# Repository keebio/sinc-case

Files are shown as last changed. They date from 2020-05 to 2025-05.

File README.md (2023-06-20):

# Sinc Keyboard Case

Here are the case design files for the [Sinc](https://keeb.io/products/sinc-split-staggered-75-keyboard). The .ai files have multiple layers to toggle on/off to generate the correct set of plates/mid-layers/etc.

It's suggested to use the enclosed design.

## Plate Files

In the [plates](plates/) folder, there are DXF files of the switch plates and bottom plates. These are the same design as the FR4 plates that are sold. The switch plates are designed for 1.5-1.6mm thickness.
## Enclosed Design

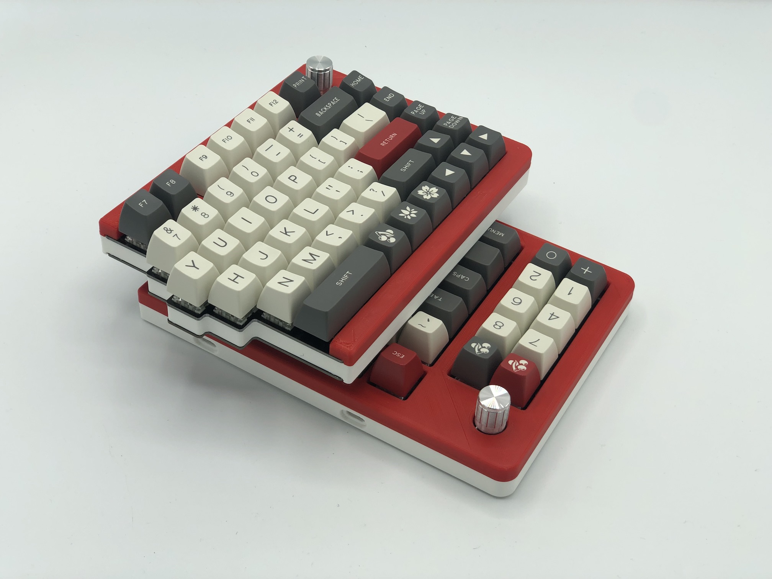
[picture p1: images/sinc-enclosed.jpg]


In the [enclosed-case](enclosed-case/) folder, there are STL files for a design where the FR4 switch and bottom plates are used but have their sides covered. The top shell has been designed to be threaded into directly from underneath using long M2 screws.

For the Rev. 2-4, you will need [M2 screws that are 16mm](https://keeb.io/products/m2-screws-and-standoffs?variant=39401487040606) in length. For Rev. 1, due to the thicker mid layer, you will need 20mm screws.

## SKUF Alignment Guide/Tool

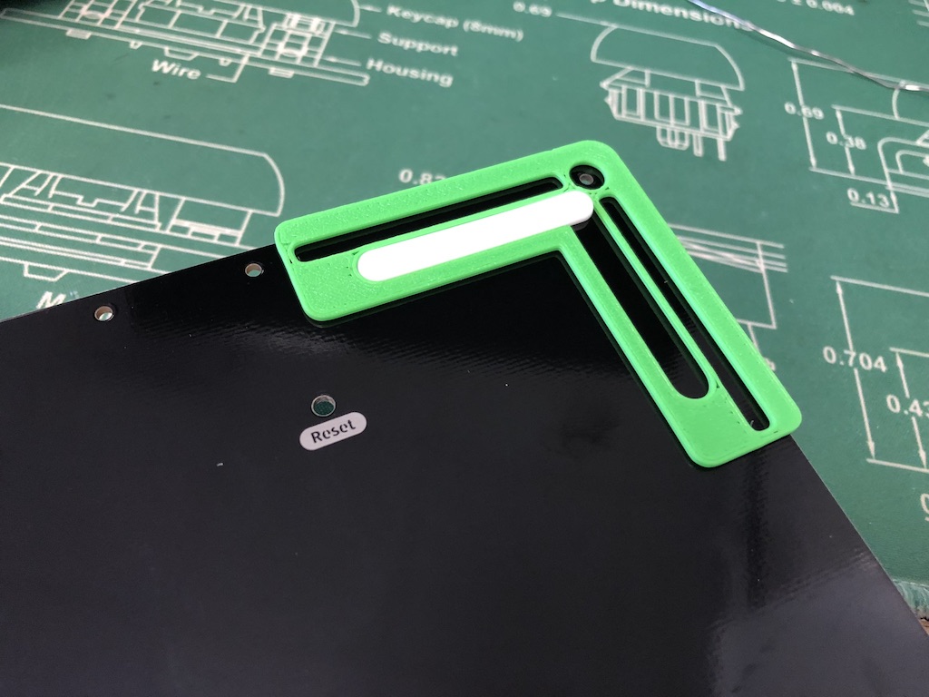
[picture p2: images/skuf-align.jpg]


For aligning the SKUF feet so that they are straight, you can print off this tool to help you apply the SKUF feet better: [SKUF Alignment Guide](SKUF%20Alignment%20Guide.stl)

## Older Design

The original case design can be found in the [older-design](older-design/) folder. The design there can be used to make a stacked acrylic case

## License

These case files are released under the MIT License.

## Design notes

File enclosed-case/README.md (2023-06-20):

Rev. 2-4 have the same PCB shape, so Rev. 2 files work fine with Rev. 3 and 4.

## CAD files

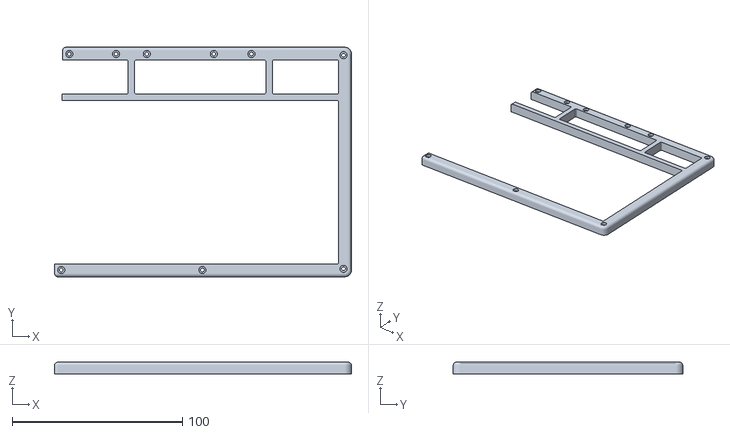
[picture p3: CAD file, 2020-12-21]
Top Shell - Right Full.stl
174.7 x 135.1 x 7.00

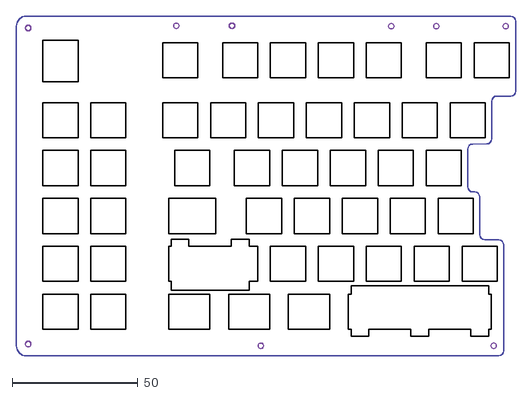
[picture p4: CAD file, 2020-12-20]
plates/5mm-plate/sinc-switch-plate-5mm-left-full.dxf
198.5 x 135.1

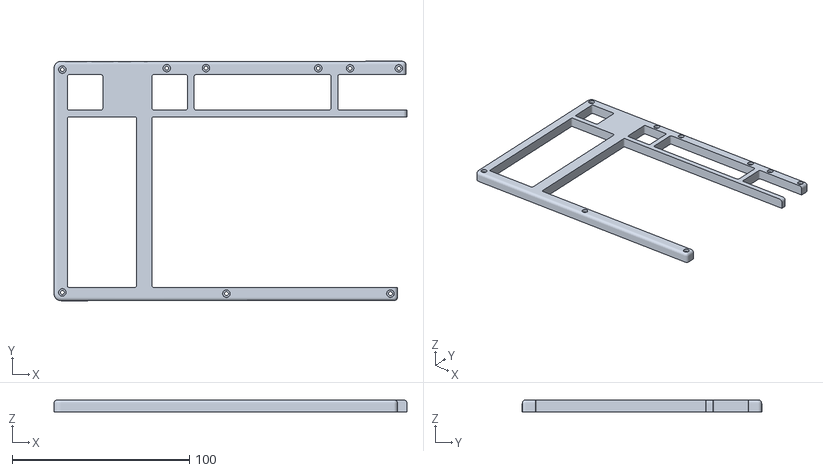
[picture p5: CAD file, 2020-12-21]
Top Shell - Left Full.stl
199.1 x 135.1 x 7.00

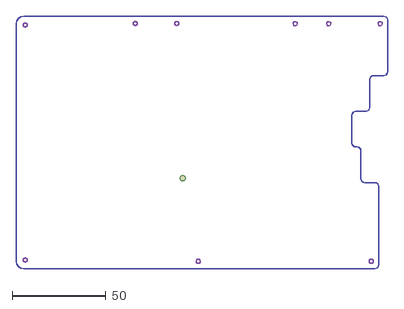
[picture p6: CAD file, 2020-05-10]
plates/sinc-bottom-plate-left-full.dxf
198.5 x 135.1

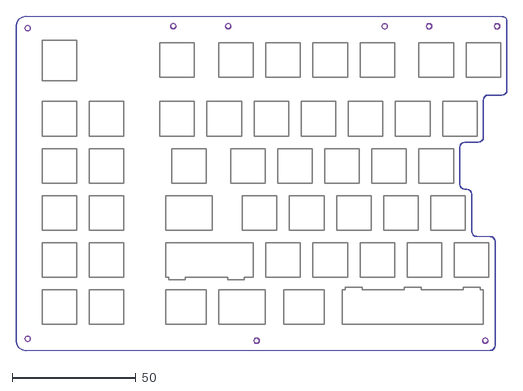
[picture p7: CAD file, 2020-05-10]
plates/sinc-switch-plate-left-full.dxf
198.5 x 135.1

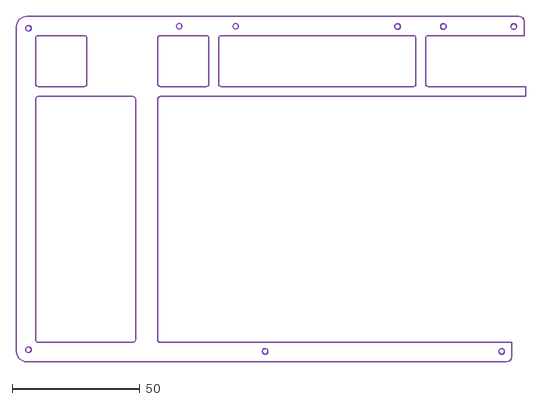
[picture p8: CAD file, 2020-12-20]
sinc-top-shell-left-full.dxf
199.1 x 135.1

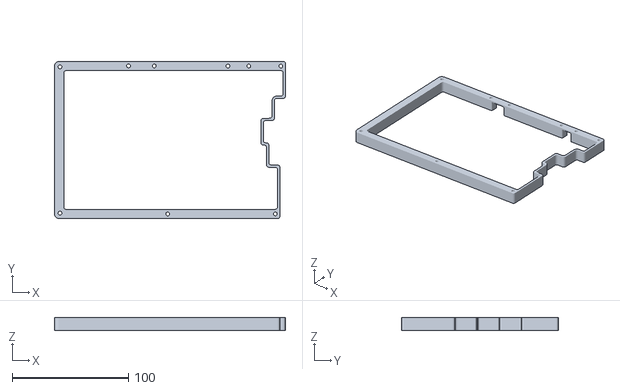
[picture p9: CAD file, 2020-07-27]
Mid - Left Full.stl
198.5 x 135.1 x 11.0

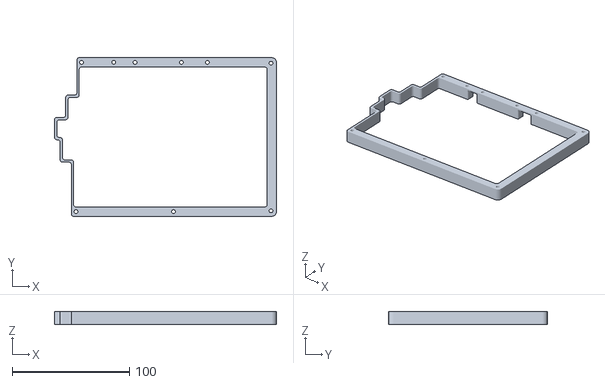
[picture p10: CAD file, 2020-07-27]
Mid - Right Full.stl
189.0 x 135.1 x 11.0

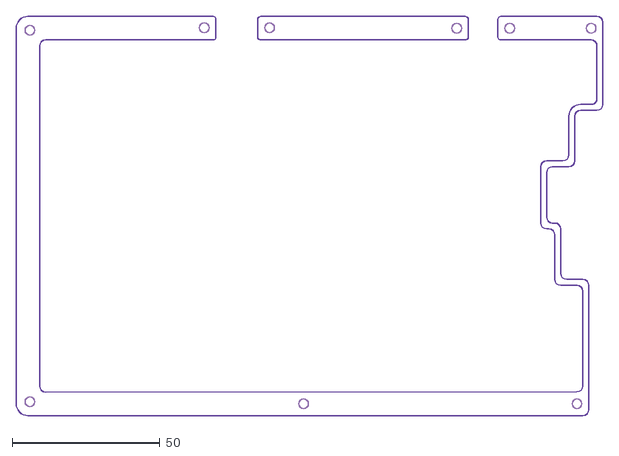
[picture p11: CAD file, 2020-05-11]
sinc-mid-layer-left-full.dxf
198.5 x 135.1

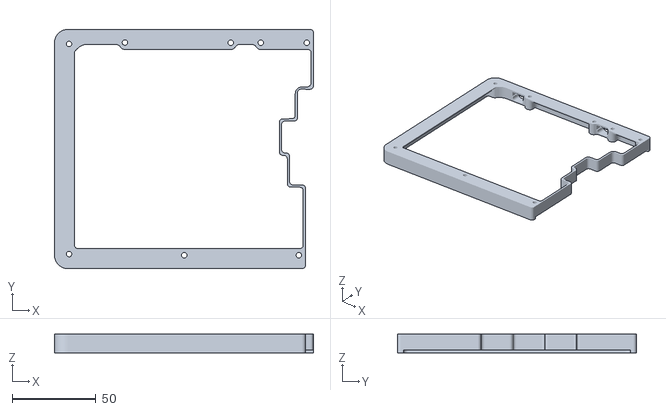
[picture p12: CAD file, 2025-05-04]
enclosed-case/Mid Layer - Rev 3-4 Left No Macro.stl
154.9 x 143.1 x 11.3

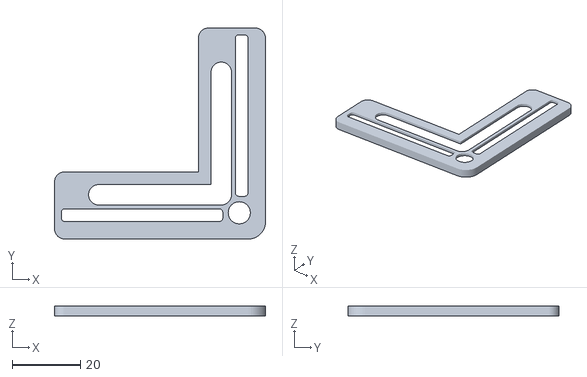
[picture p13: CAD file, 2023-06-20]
SKUF Alignment Guide.stl
62.0 x 62.0 x 3.00

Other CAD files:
plates/5mm-plate/sinc-switch-plate-5mm-right-full.dxf
plates/sinc-switch-plate-right-full.dxf
plates/sinc-bottom-plate-right-full.dxf
sinc-top-shell-right-full.dxf
sinc-mid-layer-right-full.dxf
plates/5mm-plate/sinc-switch-plate-5mm-right.dxf
plates/sinc-bottom-plate-left.dxf
Mid - Left.stl
Mid - Right.stl
Top Shell - Left.stl
Top Shell - Right.stl
enclosed-case/Mid Layer - Rev 1 Left Macro.stl
enclosed-case/Mid Layer - Rev 1 Left No Macro.stl
enclosed-case/Mid Layer - Rev 1 Right No Right Column.stl
enclosed-case/Mid Layer - Rev 1 Right.stl
enclosed-case/Mid Layer - Rev 2 Left Macro.stl
enclosed-case/Mid Layer - Rev 2 Left No Macro.stl
enclosed-case/Mid Layer - Rev 2 Right No Right Column.stl
enclosed-case/Mid Layer - Rev 2-4 Left Macro.stl
enclosed-case/Mid Layer - Rev 2-4 Left No Macro.stl
enclosed-case/Mid Layer - Rev 2-4 Right.stl
enclosed-case/Mid Layer - Rev 3-4 Left Macro.stl
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

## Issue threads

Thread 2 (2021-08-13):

New enclosure rev 1 design problem.

joonasstenvall, 2021-08-13:
The rev1 pcb connectors do not fit the current enclosure design.

## Expected Behavior
The pcb should just pop in. The tssr connector is too big for current hole. The USB-C might be problematic too.

## Current Behavior
Pcb does not go in fully when assembling. Tried to install normally but I could not get it to fix.

## Possible Solution
Enlarge the connector holes. I fixed this in a minute by plunging a soldering iron throw the holes in order to enlarge them. Would not recommend.

## Context
Was not ideal for my build. Altough I wish I did not have to enlarge the holes with an soldering iron.

nooges, 2021-08-13:
Can you take a picture and post it here? I did do a test print of https://github.com/keebio/sinc-case/blob/master/enclosed-case/Mid%20Layer%20-%20Rev%201%20Left%20Macro.stl and https://github.com/keebio/sinc-case/blob/master/enclosed-case/Mid%20Layer%20-%20Rev%201%20Right.stl, and they fit fine with my build.

joonasstenvall, 2021-08-13:
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

Sorry for the bad pictures. I have my left half fully assembled and I did not want to take it apart for a couple of pictures.
Maybe the tolerances are so tight that my printer could not print it right? But when inserting the pcb for the first time, I did get the pcb in but there was noticable collision between trrs port and the housing.

nooges, 2021-08-13:
The plate edge should not be flush with the case edge, as it should be 4mm from the edge (top shell will cover the gap). It should look like this in the end:

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

LGMagnaCarter, 2022-03-19:
Hi, I am getting a similar issue.

From looking at it, the trrs port is a square where it passes, and the case is a circle. I guess I just have to make an expansion now?
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

nooges, 2022-03-19:
As mentioned earlier in previous comment, the middle layer edge is not supposed to be flush with the plate edge. It’s 4mm extra on the sides.

LGMagnaCarter, 2022-03-19:
I understand this, but the extruding PCB that the trrs & usbc is soldered to blocks the screw holes from aligning
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

nooges, 2022-04-13:
Fixed now with https://github.com/keebio/sinc-case/commit/ac028336c68fa8048dcde10466cd0a61806cf683
These have been printed and tested with the production Rev. 1 PCB.

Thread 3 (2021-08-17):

Weird fitting with rev 1

OneMoreByte, 2021-08-17:
Hi! I think I have the same "problem" as #2. The PCB and a bit of the trrs plug seem to be pushing the case out.

Some pictures:
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

I didn't understand the resolution to #2? Is it supposed to be like that? Do I need to desolder my pcb to use this case? Is it just a bad print?

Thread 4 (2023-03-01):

will there be have the rev.3 enclosed case file released here?

darrenchiu, 2023-03-01:

PicoPlanetDev, 2023-03-02:
The rev.3 PCB is fully compatible with rev.2 plates and case, and I believe that you can just use those.

nooges, 2023-03-02:
Added README indicating this in ea03d1916f75aa313bb19794b494585239685d20

darrenchiu, 2023-03-02:
thanks!

Closed 2023-03-02.

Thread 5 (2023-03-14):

Clarify requirements for enclosed case.

Shazib, 2023-03-14:
Hi,

I have recently purchased sinc prebuilt from keeb.io which comes with the FR4 plates and have a couple queries

What are all the items i need if want to print the enclosed case? I think:

- Top Shell - Left Macro with Encodes
- Top Shell - Right with Encoder
- Mid Layer - Rev 2 Left Macro
- Mid Layer - Rev 2 Right

Questions:
1. Do i also need 'switch-plate' and 'Bottom-plate' (or are these part of the pre-built)?
2. What is the 5mm plate used for?
3. Also, is it possible to get the enclosed case files in STEP format? The place where i am sending the print requires STEP.

Many thanks!

nooges, 2023-03-17:
I've reorganized the files in the repository now and updated the README to reflect the changes, so hopefully it's clearer now.

To answer your questions:

> What are all the items i need if want to print the enclosed case? ...

The list you've got is correct.

> Do i also need 'switch-plate' and 'Bottom-plate' (or are these part of the pre-built)?

No, these are already part of the build.

> What is the 5mm plate used for?

That was for the acrylic case design.

> Also, is it possible to get the enclosed case files in STEP format? The place where i am sending the print requires STEP.

I don't have STEP files for these at the moment.

Closed 2023-03-17.

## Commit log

2020-05-10 Move right col screw/standoff hole to correct layer
2020-05-10 Add DXF files
    [sinc-bottom-plate-left-full.dxf, sinc-bottom-plate-left.dxf, sinc-bottom-plate-right-full.dxf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]
2020-05-11 Fix corner rounding on left macro mid
    [sinc-mid-layer-left-full.dxf]
2020-07-06 Add PCB STEP exports
2020-07-27 Add initial STL files for 3D printed mid
    [Mid - Left Full.stl, Mid - Left.stl, Mid - Right Full.stl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]
2020-12-20 Fix top shell files to have clearance for keycaps and add blockers for f-row gaps
    [sinc-top-shell-left-full.dxf, sinc-top-shell-left.dxf, sinc-top-shell-right-full.dxf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]
2020-12-20 Add 5mm switch plates
    [sinc-switch-plate-5mm-left-full.dxf, sinc-switch-plate-5mm-left.dxf, sinc-switch-plate-5mm-right-full.dxf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]
2020-12-21 Add 3D print top shell files
    [Top Shell - Left Full.stl, Top Shell - Left.stl, Top Shell - Right Full.stl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]
2021-07-09 Add new rev2 case files
    [Mid Layer - Rev 2 Left Macro.stl, Mid Layer - Rev 2 Right.stl, Top Shell - Left Macro with Encoder.stl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]
2021-07-22 Add Rev. 1 mid layer files
    [Mid Layer - Rev 1 Left Macro.stl, Mid Layer - Rev 1 Right.stl]
2021-08-25 Increase screw hole diameter from 1.6mm to 1.8mm, increase plate to top height from 7mm to 7.5mm
    [Top Shell - Left Macro with Encoder.stl, Top Shell - Left Macro.stl, Top Shell - Right with Encoder.stl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]
2021-08-26 Fix double wall compensation of right half parts, fix corner plate fillet insert
    [Top Shell - Left Macro with Encoder.stl, Top Shell - Left Macro.stl, Top Shell - Right with Encoder.stl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]
2021-08-30 Fix bottom plate fillet and lip for mids
    [Mid Layer - Rev 1 Left Macro.stl, Mid Layer - Rev 1 Right.stl, Mid Layer - Rev 2 Left Macro.stl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]
2021-10-15 Add top shell for left half w/o macro, increased plate slot from 1.8mm tall to 2.0mm, increased screws holes from 1.8mm to 1.9mm, changed inner keycap surround fillets to chamfers
    [Top Shell - Left Macro with Encoder.stl, Top Shell - Left Macro.stl, Top Shell - Left No Macro.stl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]
2021-10-15 Add Rev. 2 Left no macro mid
    [Mid Layer - Rev 2 Left No Macro.stl, Top Shell - Right with Encoder.stl]
2021-10-25 Add Rev. 2 PCB STEP exports, move Rev. 1 step files
2022-01-25 Add Rev. 1 mid layer for left half no macro
    [Mid Layer - Rev 1 Left No Macro.stl]
2022-04-13 Fix Sinc Rev. 1 mid layer files
    [Mid Layer - Rev 1 Left Macro.stl, Mid Layer - Rev 1 Left No Macro.stl, Mid Layer - Rev 1 Right No Right Column.stl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]
2023-03-16 Reorganize files, update README
    [Mid - Left Full.stl, Mid - Left.stl, Mid - Right Full.stl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]
2023-03-16 Move plate files
    [sinc-switch-plate-5mm-left-full.dxf, sinc-switch-plate-5mm-left.dxf, sinc-switch-plate-5mm-right-full.dxf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]
2023-06-20 Update rev numbers and add SKUF tool
    [Mid Layer - Rev 2-4 Left Macro.stl, Mid Layer - Rev 2-4 Left No Macro.stl, Mid Layer - Rev 2-4 Right.stl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]
2023-09-20 Add Rev. 4 PCB STEP files
2023-09-20 Add enclosed case files for right half w/o right column
    [Mid Layer - Rev 2 Right No Right Column.stl, Top Shell - Right No Right Column.stl]
2024-01-03 Add Fusion 360 source files
    [Top Shell - Left Full v19.f3z, Top Shell - Left No Macro - Chamfer v2.f3d, Top Shell - Right Full - Chamfer v2.f3z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]
2024-04-01 Add F360 exports of Sinc Rev. 2-4 mid-layer files
    [Mid Layer - Left Full Rev 2 v5.f3z, Mid Layer - Left No Macro Rev 2 v3.f3z, Mid Layer - Right Full Rev 2 v10.f3z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]
2025-05-04 Add revised mid-layer file for Rev. 3-4 left half
    [Mid Layer - Rev 2 Left Macro.stl, Mid Layer - Rev 2 Left No Macro.stl, Mid Layer - Rev 3-4 Left Macro - 1.4mm wall.stl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]
2025-05-04 Remove 1mm wall version, add no macro left Rev. 3-4
    [Mid Layer - Rev 3-4 Left Macro - 1.4mm wall.stl, Mid Layer - Rev 3-4 Left Macro.stl, Mid Layer - Rev 3-4 Left No Macro.stl]
